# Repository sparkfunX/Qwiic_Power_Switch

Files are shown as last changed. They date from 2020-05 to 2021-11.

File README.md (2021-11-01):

# Qwiic Power Switch

A power switch for your Qwiic system.

Qwiic Power Switch (SPX-16740) (https://www.sparkfun.com/products/16740)

[Qwiic Power Switch (SPX-16740)](https://www.sparkfun.com/products/16740)

The Qwiic Power Switch is a simple little board which can be used to switch the power to your Qwiic
system. Many Qwiic boards draw very little current when not being used, but there are some that draw
significantly more. The power switch allows you to switch the power to those boards, so you can minimize the
current draw and extend your battery life when you need to.

When the Qwiic Power Switch is turned off, the I2C wires are isolated too which prevents the pull-up
resistors from feeding parasitic power to your Qwiic boards. The power switch can also be used to
isolate a 400kHz bus from a 100kHz bus; the slower bus can be disconnected during fast-mode communication
without disabling the power.

The heart of the Qwiic Power Switch is the TI PCA9536 4-Bit I2C I/O Expander. We have broken out GPIO pins
1 and 2 so you can use them as general purpose inputs or outputs.

## Repository Contents

- **/Documents** - Datasheets etc.
- **/Hardware** - Eagle design files
- **LICENSE.md** contains the licence information

## Library

- **[Arduino Library](https://github.com/sparkfun/SparkFun_Qwiic_Power_Switch_Arduino_Library)** - Library for the power switch

## License Information

This product is _**open source**_!

Please review the LICENSE.md file for license information.

If you have any questions or concerns on licensing, please contact technical support on our [SparkFun forums](https://forum.sparkfun.com/viewforum.php?f=123).

Distributed as-is; no warranty is given.

- Your friends at SparkFun.

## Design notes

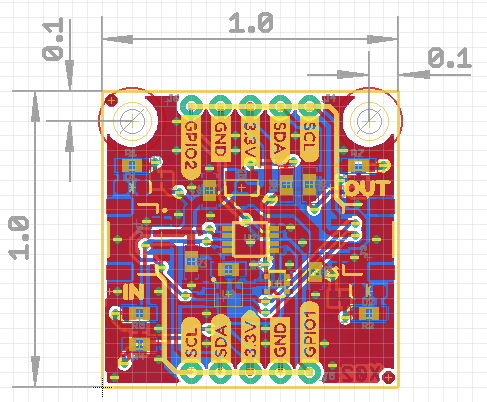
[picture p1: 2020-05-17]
img/Dimensions.PNG

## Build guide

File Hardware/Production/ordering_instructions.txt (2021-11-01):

panel size, 143x143mm
PCB thickness, 1.6mm
number of layers, 2
soldermask color, Black
silkscreen color, White
oz copper, 1oz
finish, HASL lead free
stencils, top
pcs per panel, 25
min trace width, 0.3048mm / 0.0120in
min drill size, 0.3048mm / 0.0120in

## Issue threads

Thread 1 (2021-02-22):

Investigate P-FET voltage drops

adamgarbo, 2021-02-22:
Hi @PaulZC,

A quick reminder, when time permits, to investigate the abnormally high voltage drops being experienced with the Qwiic Power Switch (QPS) when powering Qwiic devices that draw high amounts of current. Described in detail here: https://github.com/sparkfunX/Qwiic_Iridium_9603N/issues/1

Cheers,
Adam

Closed 2022-10-23.

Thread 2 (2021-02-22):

Investigate high quiescent draw

adamgarbo, 2021-02-22:
Hi @PaulZC,

Another quick note: I've been putting the Qwiic Power Switch (QPS) through its paces over the past few months and it's a very handy little board. If there are any future plans for it to "turn red", I believe it would also be worth investigating why the QPS draws upwards of ~100 uA when in its powered-down state. We've spoken about this in the past and I'd happy to try and help pin down the source of the draw.

Cheers,
Adam

Closed 2022-10-23.

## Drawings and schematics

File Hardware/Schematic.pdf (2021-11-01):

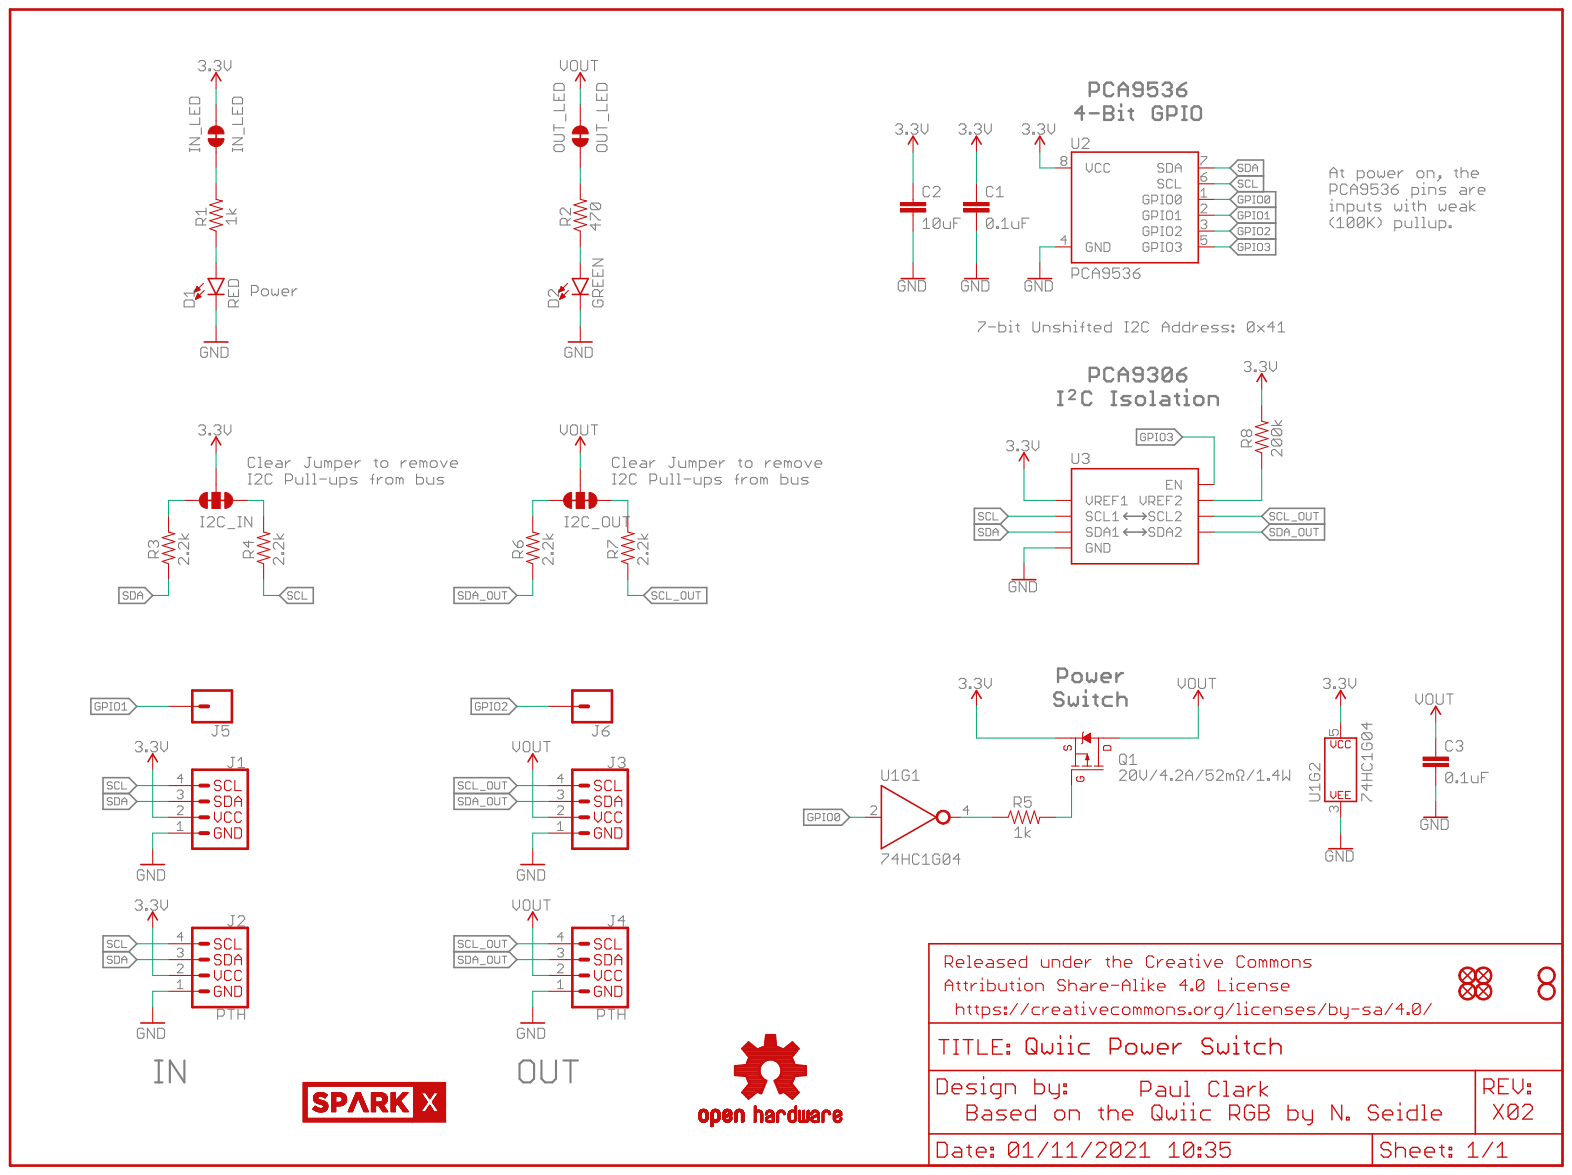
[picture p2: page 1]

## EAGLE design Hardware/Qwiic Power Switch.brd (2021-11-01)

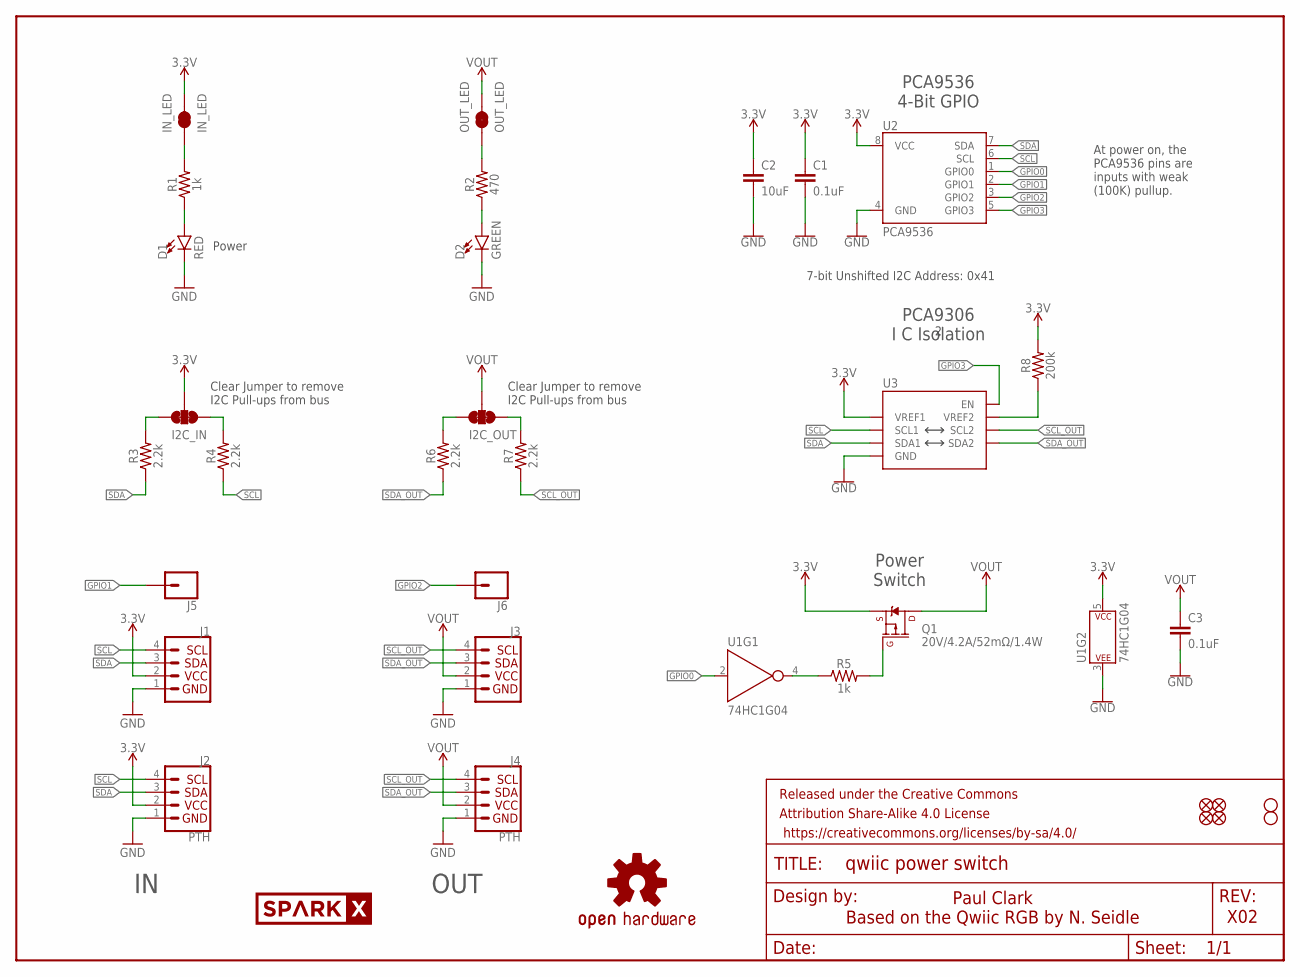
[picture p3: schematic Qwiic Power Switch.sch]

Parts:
C1, C3: 0.1uF; 0603
C2: 10uF; 0603
D1: RED; LED-0603
D2: GREEN; LED-0603
FRAME1: FRAME-LETTER; CREATIVE_COMMONS
I2C_IN, I2C_OUT: JUMPER-SMT_3_2-NC_TRACE_SILK; SMT-JUMPER_3_2-NC_TRACE_SILK
IN_LED: IN_LED; SMT-JUMPER_2_NC_TRACE_SILK
J1, J3: Qwiic Right Angle; JST04_1MM_RA
J2, J4: PTH; 1X04_NO_SILK
J5, J6: CONN_01PTH_NO_SILK_YES_STOP; 1X01_NO_SILK
JP1, JP2, JP5, JP6: FIDUCIAL1X2; FIDUCIAL-1X2
JP3, JP4: STAND-OFF
LOGO1: OSHW-LOGOMINI; OSHW-LOGO-MINI
OUT_LED: OUT_LED; SMT-JUMPER_2_NC_TRACE_SILK
Q1: 20V/4.2A/52mΩ/1.4W; SOT23-3
R1, R5: 1k; 0603
R2: 470; 0603
R3, R4, R6, R7: 2.2k; 0603
R8: 200k; 0603
U1: 74HC1G04; SOT353
U2: PCA9536; MSOP8
U3: PCA9306VSSOP_8PIN; VSSOP_8PIN
U$2: SPARKX-LOGO4; SPARKX-MEDIUM

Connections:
3.3V: C1.1, C2.1, I2C_IN.2, IN_LED.2, J1.2, J2.2, Q1.2 (S), R8.2, U1.5 (P$V+), U2.8 (VCC), U3.P2 (VREF1)
GND: C1.2, C2.2, C3.2, D1.C, D2.C, J1.1, J2.1, J3.1, J4.1, U1.3 (P$V-), U2.4 (GND), U3.P1 (GND)
GPIO0: U1.2 (A), U2.1 (GPIO0)
GPIO1: J5.1, U2.2 (GPIO1)
GPIO2: J6.1, U2.3 (GPIO2)
GPIO3: U2.5 (GPIO3), U3.P8 (EN)
unnamed: I2C_IN.1, R4.2
unnamed: I2C_IN.3, R3.2
unnamed: D1.A, R1.1
unnamed: IN_LED.1, R1.2
unnamed: R5.1, U1.4 (Y)
unnamed: Q1.1 (G), R5.2
unnamed: OUT_LED.1, R2.2
unnamed: I2C_OUT.1, R7.2
unnamed: D2.A, R2.1
unnamed: I2C_OUT.3, R6.2
unnamed: R8.1, U3.P7 (VREF2)
SCL: J1.4, J2.4, R4.1, U2.6 (SCL), U3.P3 (SCL1)
SCL_OUT: J3.4, J4.4, R7.1, U3.P6 (SCL2)
SDA: J1.3, J2.3, R3.1, U2.7 (SDA), U3.P4 (SDA1)
SDA_OUT: J3.3, J4.3, R6.1, U3.P5 (SDA2)
VOUT: C3.1, I2C_OUT.2, J3.2, J4.2, OUT_LED.2, Q1.3 (D)

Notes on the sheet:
Paul Clark Based on the Qwiic RGB by N. Seidle
X02
Clear Jumper to remove I2C Pull-ups from bus
Power
7-bit Unshifted I2C Address: 0x41
OUT
At power on, the PCA9536 pins are inputs with weak (100K) pullup.
PCA9536 4-Bit GPIO
PCA9306 I C Isolation
Power Switch

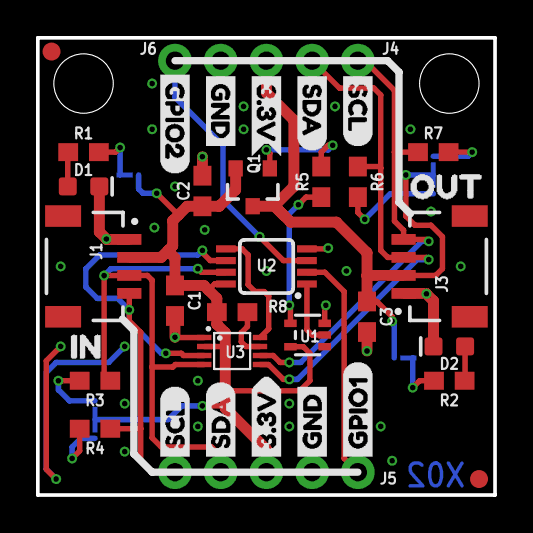
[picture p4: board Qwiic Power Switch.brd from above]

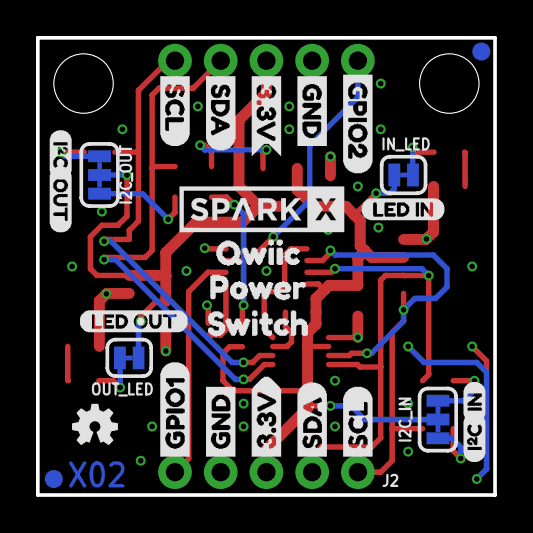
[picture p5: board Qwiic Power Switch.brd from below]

Board: 2 copper layers, 25.4 x 25.4 mm, 67 parts (28 on the bottom side), 22 nets.

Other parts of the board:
U$1, U$28: IN0
U$3, U$8, U$13, U$22: GND1
U$4, U$7, U$12, U$23: 3#3V0
U$5, U$11, U$15, U$27: SDA8
U$6, U$9, U$17, U$26: SCL9
U$10, U$18: I_SUPER2_C-()-03
U$14, U$31: OUT0
U$16, U$24: GPIO10
U$19: QWIIC0
U$20, U$25: GPIO20
U$29: LED_IN0
U$30: LED_OUT0
U$32: POWER0
U$34: SWITCH0

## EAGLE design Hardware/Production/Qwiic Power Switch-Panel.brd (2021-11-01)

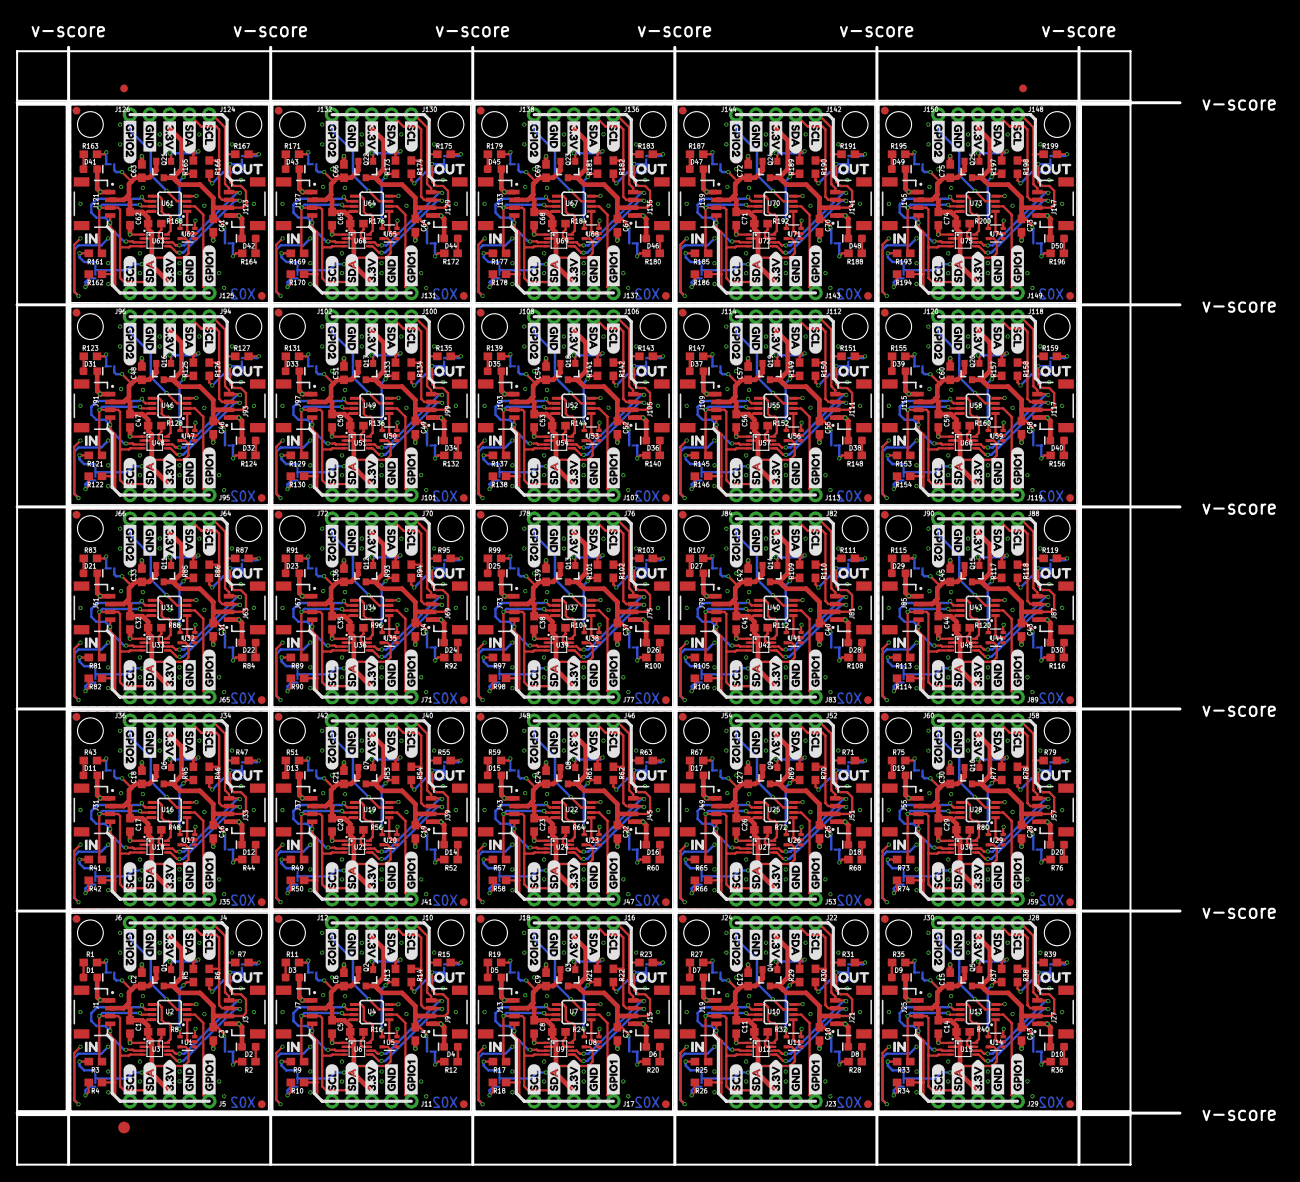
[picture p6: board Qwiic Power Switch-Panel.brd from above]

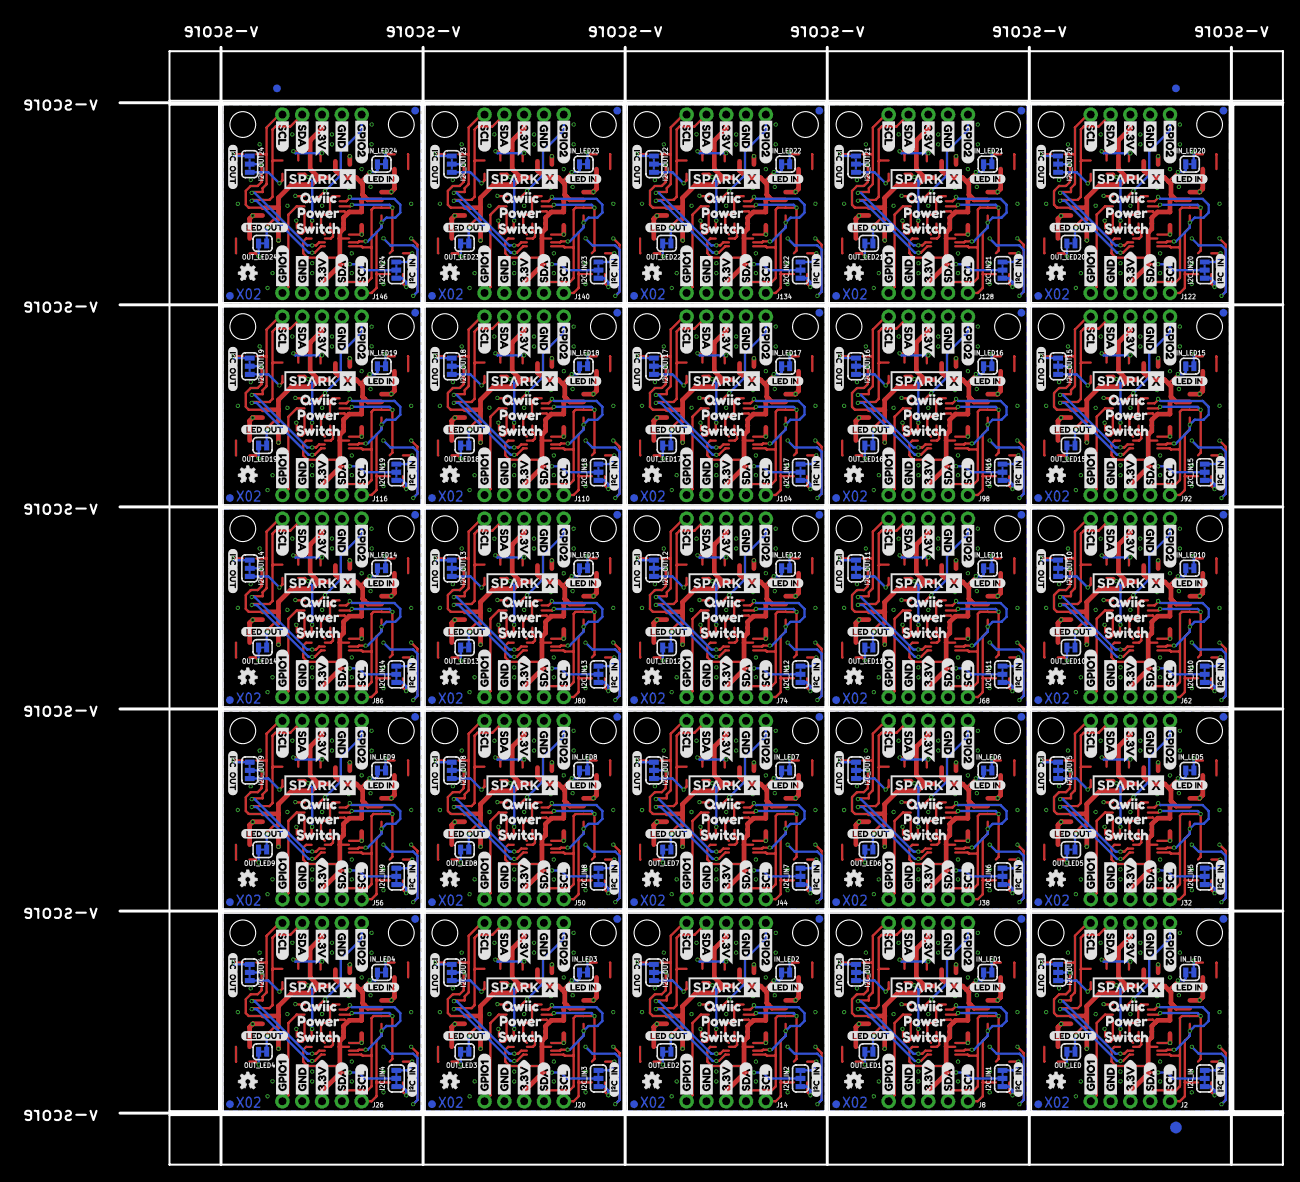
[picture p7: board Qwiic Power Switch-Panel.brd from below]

Board: 2 copper layers, 149.1 x 143.3 mm, 1656 parts (703 on the bottom side), 550 nets.

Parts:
C1, C3, C4, C5, C7, C8, C10, C11, C13, C14, C16, C17, C19, C20, C22, C23, C25, C26, C28, C29, C31, C32, C34, C35, C37, C38, C40, C41, C43, C44, C46, C47, C49, C50, C52, C53, C55, C56, C58, C59, C61, C62, C64, C65, C67, C68, C70, C71, C73, C74: 0.1uF; 0603
C2, C6, C9, C12, C15, C18, C21, C24, C27, C30, C33, C36, C39, C42, C45, C48, C51, C54, C57, C60, C63, C66, C69, C72, C75: 10uF; 0603
D1, D3, D5, D7, D9, D11, D13, D15, D17, D19, D21, D23, D25, D27, D29, D31, D33, D35, D37, D39, D41, D43, D45, D47, D49: RED; LED-0603
D2, D4, D6, D8, D10, D12, D14, D16, D18, D20, D22, D24, D26, D28, D30, D32, D34, D36, D38, D40, D42, D44, D46, D48, D50: GREEN; LED-0603
E$1, E$2, E$3, E$4: FIDUCIAL-1X2
E$5, E$6: FIDUCIAL-1.5X3
I2C_IN, I2C_IN1, I2C_IN2, I2C_IN3, I2C_IN4, I2C_IN5, I2C_IN6, I2C_IN7, I2C_IN8, I2C_IN9, I2C_IN10, I2C_IN11, I2C_IN12, I2C_IN13, I2C_IN14, I2C_IN15, I2C_IN16, I2C_IN17, I2C_IN18, I2C_IN19, I2C_IN20, I2C_IN21, I2C_IN22, I2C_IN23, I2C_IN24, I2C_OUT, I2C_OUT1, I2C_OUT2, I2C_OUT3, I2C_OUT4, I2C_OUT5, I2C_OUT6, I2C_OUT7, I2C_OUT8, I2C_OUT9, I2C_OUT10, I2C_OUT11, I2C_OUT12, I2C_OUT13, I2C_OUT14, I2C_OUT15, I2C_OUT16, I2C_OUT17, I2C_OUT18, I2C_OUT19, I2C_OUT20, I2C_OUT21, I2C_OUT22, I2C_OUT23, I2C_OUT24: JUMPER-SMT_3_2-NC_TRACE_SILK; SMT-JUMPER_3_2-NC_TRACE_SILK
IN_LED, IN_LED1, IN_LED2, IN_LED3, IN_LED4, IN_LED5, IN_LED6, IN_LED7, IN_LED8, IN_LED9, IN_LED10, IN_LED11, IN_LED12, IN_LED13, IN_LED14, IN_LED15, IN_LED16, IN_LED17, IN_LED18, IN_LED19, IN_LED20, IN_LED21, IN_LED22, IN_LED23, IN_LED24: IN_LED; SMT-JUMPER_2_NC_TRACE_SILK
J1, J3, J7, J9, J13, J15, J19, J21, J25, J27, J31, J33, J37, J39, J43, J45, J49, J51, J55, J57, J61, J63, J67, J69, J73, J75, J79, J81, J85, J87, J91, J93, J97, J99, J103, J105, J109, J111, J115, J117, J121, J123, J127, J129, J133, J135, J139, J141, J145, J147: Qwiic Right Angle; JST04_1MM_RA
J2, J4, J8, J10, J14, J16, J20, J22, J26, J28, J32, J34, J38, J40, J44, J46, J50, J52, J56, J58, J62, J64, J68, J70, J74, J76, J80, J82, J86, J88, J92, J94, J98, J100, J104, J106, J110, J112, J116, J118, J122, J124, J128, J130, J134, J136, J140, J142, J146, J148: PTH; 1X04_NO_SILK
J5, J6, J11, J12, J17, J18, J23, J24, J29, J30, J35, J36, J41, J42, J47, J48, J53, J54, J59, J60, J65, J66, J71, J72, J77, J78, J83, J84, J89, J90, J95, J96, J101, J102, J107, J108, J113, J114, J119, J120, J125, J126, J131, J132, J137, J138, J143, J144, J149, J150: 1X01_NO_SILK
JP1, JP2, JP5, JP6, JP9, JP10, JP11, JP12, JP15, JP16, JP17, JP18, JP21, JP22, JP23, JP24, JP27, JP28, JP29, JP30, JP33, JP34, JP35, JP36, JP39, JP40, JP41, JP42, JP45, JP46, JP47, JP48, JP51, JP52, JP53, JP54, JP57, JP58, JP59, JP60, JP63, JP64, JP65, JP66, JP69, JP70, JP71, JP72, JP75, JP76, JP77, JP78, JP81, JP82, JP83, JP84, JP87, JP88, JP89, JP90, JP93, JP94, JP95, JP96, JP99, JP100, JP101, JP102, JP105, JP106, JP107, JP108, JP111, JP112, JP113, JP114, JP117, JP118, JP119, JP120, JP123, JP124, JP125, JP126, JP129, JP130, JP131, JP132, JP135, JP136, JP137, JP138, JP141, JP142, JP143, JP144, JP147, JP148, JP149, JP150: FIDUCIAL1X2; FIDUCIAL-1X2
JP3, JP4, JP7, JP8, JP13, JP14, JP19, JP20, JP25, JP26, JP31, JP32, JP37, JP38, JP43, JP44, JP49, JP50, JP55, JP56, JP61, JP62, JP67, JP68, JP73, JP74, JP79, JP80, JP85, JP86, JP91, JP92, JP97, JP98, JP103, JP104, JP109, JP110, JP115, JP116, JP121, JP122, JP127, JP128, JP133, JP134, JP139, JP140, JP145, JP146: STAND-OFF
LOGO1, LOGO2, LOGO3, LOGO4, LOGO5, LOGO6, LOGO7, LOGO8, LOGO9, LOGO10, LOGO11, LOGO12, LOGO13, LOGO14, LOGO15, LOGO16, LOGO17, LOGO18, LOGO19, LOGO20, LOGO21, LOGO22, LOGO23, LOGO24, LOGO25: OSHW-LOGOMINI; OSHW-LOGO-MINI
OUT_LED, OUT_LED1, OUT_LED2, OUT_LED3, OUT_LED4, OUT_LED5, OUT_LED6, OUT_LED7, OUT_LED8, OUT_LED9, OUT_LED10, OUT_LED11, OUT_LED12, OUT_LED13, OUT_LED14, OUT_LED15, OUT_LED16, OUT_LED17, OUT_LED18, OUT_LED19, OUT_LED20, OUT_LED21, OUT_LED22, OUT_LED23, OUT_LED24: OUT_LED; SMT-JUMPER_2_NC_TRACE_SILK
Q1, Q2, Q3, Q4, Q5, Q6, Q7, Q8, Q9, Q10, Q11, Q12, Q13, Q14, Q15, Q16, Q17, Q18, Q19, Q20, Q21, Q22, Q23, Q24, Q25: 20V/4.2A/52mΩ/1.4W; SOT23-3
R1, R5, R11, R13, R19, R21, R27, R29, R35, R37, R43, R45, R51, R53, R59, R61, R67, R69, R75, R77, R83, R85, R91, R93, R99, R101, R107, R109, R115, R117, R123, R125, R131, R133, R139, R141, R147, R149, R155, R157, R163, R165, R171, R173, R179, R181, R187, R189, R195, R197: 1k; 0603
R2, R12, R20, R28, R36, R44, R52, R60, R68, R76, R84, R92, R100, R108, R116, R124, R132, R140, R148, R156, R164, R172, R180, R188, R196: 470; 0603
R3, R4, R6, R7, R9, R10, R14, R15, R17, R18, R22, R23, R25, R26, R30, R31, R33, R34, R38, R39, R41, R42, R46, R47, R49, R50, R54, R55, R57, R58, R62, R63, R65, R66, R70, R71, R73, R74, R78, R79, R81, R82, R86, R87, R89, R90, R94, R95, R97, R98, R102, R103, R105, R106, R110, R111, R113, R114, R118, R119, R121, R122, R126, R127, R129, R130, R134, R135, R137, R138, R142, R143, R145, R146, R150, R151, R153, R154, R158, R159, R161, R162, R166, R167, R169, R170, R174, R175, R177, R178, R182, R183, R185, R186, R190, R191, R193, R194, R198, R199: 2.2k; 0603
R8, R16, R24, R32, R40, R48, R56, R64, R72, R80, R88, R96, R104, R112, R120, R128, R136, R144, R152, R160, R168, R176, R184, R192, R200: 200k; 0603
U1, U5, U8, U11, U14, U17, U20, U23, U26, U29, U32, U35, U38, U41, U44, U47, U50, U53, U56, U59, U62, U65, U68, U71, U74: 74HC1G04; SOT353
U2, U4, U7, U10, U13, U16, U19, U22, U25, U28, U31, U34, U37, U40, U43, U46, U49, U52, U55, U58, U61, U64, U67, U70, U73: PCA9536; MSOP8
U3, U6, U9, U12, U15, U18, U21, U24, U27, U30, U33, U36, U39, U42, U45, U48, U51, U54, U57, U60, U63, U66, U69, U72, U75: VSSOP_8PIN
U$1, U$28, U$52, U$62, U$84, U$94, U$116, U$126, U$148, U$158, U$180, U$190, U$212, U$222, U$244, U$254, U$276, U$286, U$308, U$318, U$340, U$350, U$372, U$382, U$404, U$414, U$436, U$446, U$468, U$478, U$500, U$510, U$532, U$542, U$564, U$574, U$596, U$606, U$628, U$638, U$660, U$670, U$692, U$702, U$724, U$734, U$756, U$766, U$788, U$798: IN0
U$2, U$21, U$65, U$97, U$129, U$161, U$193, U$225, U$257, U$289, U$321, U$353, U$385, U$417, U$449, U$481, U$513, U$545, U$577, U$609, U$641, U$673, U$705, U$737, U$769: SPARKX-LOGO4; SPARKX-MEDIUM
U$3, U$8, U$13, U$22, U$33, U$37, U$41, U$44, U$66, U$69, U$73, U$76, U$98, U$101, U$105, U$108, U$130, U$133, U$137, U$140, U$162, U$165, U$169, U$172, U$194, U$197, U$201, U$204, U$226, U$229, U$233, U$236, U$258, U$261, U$265, U$268, U$290, U$293, U$297, U$300, U$322, U$325, U$329, U$332, U$354, U$357, U$361, U$364, U$386, U$389, U$393, U$396, U$418, U$421, U$425, U$428, U$450, U$453, U$457, U$460, U$482, U$485, U$489, U$492, U$514, U$517, U$521, U$524, U$546, U$549, U$553, U$556, U$578, U$581, U$585, U$588, U$610, U$613, U$617, U$620, U$642, U$645, U$649, U$652, U$674, U$677, U$681, U$684, U$706, U$709, U$713, U$716, U$738, U$741, U$745, U$748, U$770, U$773, U$777, U$780: GND1
U$4, U$7, U$12, U$23, U$48, U$49, U$60, U$61, U$80, U$81, U$92, U$93, U$112, U$113, U$124, U$125, U$144, U$145, U$156, U$157, U$176, U$177, U$188, U$189, U$208, U$209, U$220, U$221, U$240, U$241, U$252, U$253, U$272, U$273, U$284, U$285, U$304, U$305, U$316, U$317, U$336, U$337, U$348, U$349, U$368, U$369, U$380, U$381, U$400, U$401, U$412, U$413, U$432, U$433, U$444, U$445, U$464, U$465, U$476, U$477, U$496, U$497, U$508, U$509, U$528, U$529, U$540, U$541, U$560, U$561, U$572, U$573, U$592, U$593, U$604, U$605, U$624, U$625, U$636, U$637, U$656, U$657, U$668, U$669, U$688, U$689, U$700, U$701, U$720, U$721, U$732, U$733, U$752, U$753, U$764, U$765, U$784, U$785, U$796, U$797: 3#3V0
U$5, U$11, U$15, U$27, U$36, U$38, U$43, U$45, U$68, U$70, U$75, U$77, U$100, U$102, U$107, U$109, U$132, U$134, U$139, U$141, U$164, U$166, U$171, U$173, U$196, U$198, U$203, U$205, U$228, U$230, U$235, U$237, U$260, U$262, U$267, U$269, U$292, U$294, U$299, U$301, U$324, U$326, U$331, U$333, U$356, U$358, U$363, U$365, U$388, U$390, U$395, U$397, U$420, U$422, U$427, U$429, U$452, U$454, U$459, U$461, U$484, U$486, U$491, U$493, U$516, U$518, U$523, U$525, U$548, U$550, U$555, U$557, U$580, U$582, U$587, U$589, U$612, U$614, U$619, U$621, U$644, U$646, U$651, U$653, U$676, U$678, U$683, U$685, U$708, U$710, U$715, U$717, U$740, U$742, U$747, U$749, U$772, U$774, U$779, U$781: SDA8
U$6, U$9, U$17, U$26, U$35, U$39, U$42, U$46, U$67, U$71, U$74, U$78, U$99, U$103, U$106, U$110, U$131, U$135, U$138, U$142, U$163, U$167, U$170, U$174, U$195, U$199, U$202, U$206, U$227, U$231, U$234, U$238, U$259, U$263, U$266, U$270, U$291, U$295, U$298, U$302, U$323, U$327, U$330, U$334, U$355, U$359, U$362, U$366, U$387, U$391, U$394, U$398, U$419, U$423, U$426, U$430, U$451, U$455, U$458, U$462, U$483, U$487, U$490, U$494, U$515, U$519, U$522, U$526, U$547, U$551, U$554, U$558, U$579, U$583, U$586, U$590, U$611, U$615, U$618, U$622, U$643, U$647, U$650, U$654, U$675, U$679, U$682, U$686, U$707, U$711, U$714, U$718, U$739, U$743, U$746, U$750, U$771, U$775, U$778, U$782: SCL9
U$10, U$18, U$40, U$64, U$72, U$96, U$104, U$128, U$136, U$160, U$168, U$192, U$200, U$224, U$232, U$256, U$264, U$288, U$296, U$320, U$328, U$352, U$360, U$384, U$392, U$416, U$424, U$448, U$456, U$480, U$488, U$512, U$520, U$544, U$552, U$576, U$584, U$608, U$616, U$640, U$648, U$672, U$680, U$704, U$712, U$736, U$744, U$768, U$776, U$800: I_SUPER2_C-()-03
U$14, U$31, U$55, U$63, U$87, U$95, U$119, U$127, U$151, U$159, U$183, U$191, U$215, U$223, U$247, U$255, U$279, U$287, U$311, U$319, U$343, U$351, U$375, U$383, U$407, U$415, U$439, U$447, U$471, U$479, U$503, U$511, U$535, U$543, U$567, U$575, U$599, U$607, U$631, U$639, U$663, U$671, U$695, U$703, U$727, U$735, U$759, U$767, U$791, U$799: OUT0
U$16, U$24, U$50, U$58, U$82, U$90, U$114, U$122, U$146, U$154, U$178, U$186, U$210, U$218, U$242, U$250, U$274, U$282, U$306, U$314, U$338, U$346, U$370, U$378, U$402, U$410, U$434, U$442, U$466, U$474, U$498, U$506, U$530, U$538, U$562, U$570, U$594, U$602, U$626, U$634, U$658, U$666, U$690, U$698, U$722, U$730, U$754, U$762, U$786, U$794: GPIO10
U$19, U$47, U$79, U$111, U$143, U$175, U$207, U$239, U$271, U$303, U$335, U$367, U$399, U$431, U$463, U$495, U$527, U$559, U$591, U$623, U$655, U$687, U$719, U$751, U$783: QWIIC0
U$20, U$25, U$51, U$59, U$83, U$91, U$115, U$123, U$147, U$155, U$179, U$187, U$211, U$219, U$243, U$251, U$275, U$283, U$307, U$315, U$339, U$347, U$371, U$379, U$403, U$411, U$435, U$443, U$467, U$475, U$499, U$507, U$531, U$539, U$563, U$571, U$595, U$603, U$627, U$635, U$659, U$667, U$691, U$699, U$723, U$731, U$755, U$763, U$787, U$795: GPIO20
U$29, U$53, U$85, U$117, U$149, U$181, U$213, U$245, U$277, U$309, U$341, U$373, U$405, U$437, U$469, U$501, U$533, U$565, U$597, U$629, U$661, U$693, U$725, U$757, U$789: LED_IN0
U$30, U$54, U$86, U$118, U$150, U$182, U$214, U$246, U$278, U$310, U$342, U$374, U$406, U$438, U$470, U$502, U$534, U$566, U$598, U$630, U$662, U$694, U$726, U$758, U$790: LED_OUT0
U$32, U$56, U$88, U$120, U$152, U$184, U$216, U$248, U$280, U$312, U$344, U$376, U$408, U$440, U$472, U$504, U$536, U$568, U$600, U$632, U$664, U$696, U$728, U$760, U$792: POWER0
U$34, U$57, U$89, U$121, U$153, U$185, U$217, U$249, U$281, U$313, U$345, U$377, U$409, U$441, U$473, U$505, U$537, U$569, U$601, U$633, U$665, U$697, U$729, U$761, U$793: SWITCH0

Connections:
3.3V: C1.1, C2.1, I2C_IN.2, IN_LED.2, J1.2, J2.2, Q1.2, R8.2, U1.5, U2.8, U3.P2
3.3V1: C5.1, C6.1, I2C_IN1.2, IN_LED1.2, J7.2, J8.2, Q2.2, R16.2, U4.8, U5.5, U6.P2
3.3V2: C8.1, C9.1, I2C_IN2.2, IN_LED2.2, J13.2, J14.2, Q3.2, R24.2, U7.8, U8.5, U9.P2
3.3V3: C11.1, C12.1, I2C_IN3.2, IN_LED3.2, J19.2, J20.2, Q4.2, R32.2, U10.8, U11.5, U12.P2
3.3V4: C14.1, C15.1, I2C_IN4.2, IN_LED4.2, J25.2, J26.2, Q5.2, R40.2, U13.8, U14.5, U15.P2
3.3V5: C17.1, C18.1, I2C_IN5.2, IN_LED5.2, J31.2, J32.2, Q6.2, R48.2, U16.8, U17.5, U18.P2
3.3V6: C20.1, C21.1, I2C_IN6.2, IN_LED6.2, J37.2, J38.2, Q7.2, R56.2, U19.8, U20.5, U21.P2
3.3V7: C23.1, C24.1, I2C_IN7.2, IN_LED7.2, J43.2, J44.2, Q8.2, R64.2, U22.8, U23.5, U24.P2
3.3V8: C26.1, C27.1, I2C_IN8.2, IN_LED8.2, J49.2, J50.2, Q9.2, R72.2, U25.8, U26.5, U27.P2
3.3V9: C29.1, C30.1, I2C_IN9.2, IN_LED9.2, J55.2, J56.2, Q10.2, R80.2, U28.8, U29.5, U30.P2
3.3V10: C32.1, C33.1, I2C_IN10.2, IN_LED10.2, J61.2, J62.2, Q11.2, R88.2, U31.8, U32.5, U33.P2
3.3V11: C35.1, C36.1, I2C_IN11.2, IN_LED11.2, J67.2, J68.2, Q12.2, R96.2, U34.8, U35.5, U36.P2
3.3V12: C38.1, C39.1, I2C_IN12.2, IN_LED12.2, J73.2, J74.2, Q13.2, R104.2, U37.8, U38.5, U39.P2
3.3V13: C41.1, C42.1, I2C_IN13.2, IN_LED13.2, J79.2, J80.2, Q14.2, R112.2, U40.8, U41.5, U42.P2
3.3V14: C44.1, C45.1, I2C_IN14.2, IN_LED14.2, J85.2, J86.2, Q15.2, R120.2, U43.8, U44.5, U45.P2
3.3V15: C47.1, C48.1, I2C_IN15.2, IN_LED15.2, J91.2, J92.2, Q16.2, R128.2, U46.8, U47.5, U48.P2
3.3V16: C50.1, C51.1, I2C_IN16.2, IN_LED16.2, J97.2, J98.2, Q17.2, R136.2, U49.8, U50.5, U51.P2
3.3V17: C53.1, C54.1, I2C_IN17.2, IN_LED17.2, J103.2, J104.2, Q18.2, R144.2, U52.8, U53.5, U54.P2
3.3V18: C56.1, C57.1, I2C_IN18.2, IN_LED18.2, J109.2, J110.2, Q19.2, R152.2, U55.8, U56.5, U57.P2
3.3V19: C59.1, C60.1, I2C_IN19.2, IN_LED19.2, J115.2, J116.2, Q20.2, R160.2, U58.8, U59.5, U60.P2
3.3V20: C62.1, C63.1, I2C_IN20.2, IN_LED20.2, J121.2, J122.2, Q21.2, R168.2, U61.8, U62.5, U63.P2
3.3V21: C65.1, C66.1, I2C_IN21.2, IN_LED21.2, J127.2, J128.2, Q22.2, R176.2, U64.8, U65.5, U66.P2
3.3V22: C68.1, C69.1, I2C_IN22.2, IN_LED22.2, J133.2, J134.2, Q23.2, R184.2, U67.8, U68.5, U69.P2
3.3V23: C71.1, C72.1, I2C_IN23.2, IN_LED23.2, J139.2, J140.2, Q24.2, R192.2, U70.8, U71.5, U72.P2
3.3V24: C74.1, C75.1, I2C_IN24.2, IN_LED24.2, J145.2, J146.2, Q25.2, R200.2, U73.8, U74.5, U75.P2
GND: C1.2, C2.2, C3.2, D1.C, D2.C, J1.1, J2.1, J3.1, J4.1, U1.3, U2.4, U3.P1
GND1: C4.2, C5.2, C6.2, D3.C, D4.C, J7.1, J8.1, J9.1, J10.1, U4.4, U5.3, U6.P1
GND2: C7.2, C8.2, C9.2, D5.C, D6.C, J13.1, J14.1, J15.1, J16.1, U7.4, U8.3, U9.P1
GND3: C10.2, C11.2, C12.2, D7.C, D8.C, J19.1, J20.1, J21.1, J22.1, U10.4, U11.3, U12.P1
GND4: C13.2, C14.2, C15.2, D9.C, D10.C, J25.1, J26.1, J27.1, J28.1, U13.4, U14.3, U15.P1
GND5: C16.2, C17.2, C18.2, D11.C, D12.C, J31.1, J32.1, J33.1, J34.1, U16.4, U17.3, U18.P1
GND6: C19.2, C20.2, C21.2, D13.C, D14.C, J37.1, J38.1, J39.1, J40.1, U19.4, U20.3, U21.P1
GND7: C22.2, C23.2, C24.2, D15.C, D16.C, J43.1, J44.1, J45.1, J46.1, U22.4, U23.3, U24.P1
GND8: C25.2, C26.2, C27.2, D17.C, D18.C, J49.1, J50.1, J51.1, J52.1, U25.4, U26.3, U27.P1
GND9: C28.2, C29.2, C30.2, D19.C, D20.C, J55.1, J56.1, J57.1, J58.1, U28.4, U29.3, U30.P1
GND10: C31.2, C32.2, C33.2, D21.C, D22.C, J61.1, J62.1, J63.1, J64.1, U31.4, U32.3, U33.P1
GND11: C34.2, C35.2, C36.2, D23.C, D24.C, J67.1, J68.1, J69.1, J70.1, U34.4, U35.3, U36.P1
GND12: C37.2, C38.2, C39.2, D25.C, D26.C, J73.1, J74.1, J75.1, J76.1, U37.4, U38.3, U39.P1
GND13: C40.2, C41.2, C42.2, D27.C, D28.C, J79.1, J80.1, J81.1, J82.1, U40.4, U41.3, U42.P1
GND14: C43.2, C44.2, C45.2, D29.C, D30.C, J85.1, J86.1, J87.1, J88.1, U43.4, U44.3, U45.P1
GND15: C46.2, C47.2, C48.2, D31.C, D32.C, J91.1, J92.1, J93.1, J94.1, U46.4, U47.3, U48.P1
GND16: C49.2, C50.2, C51.2, D33.C, D34.C, J97.1, J98.1, J99.1, J100.1, U49.4, U50.3, U51.P1
GND17: C52.2, C53.2, C54.2, D35.C, D36.C, J103.1, J104.1, J105.1, J106.1, U52.4, U53.3, U54.P1
GND18: C55.2, C56.2, C57.2, D37.C, D38.C, J109.1, J110.1, J111.1, J112.1, U55.4, U56.3, U57.P1
GND19: C58.2, C59.2, C60.2, D39.C, D40.C, J115.1, J116.1, J117.1, J118.1, U58.4, U59.3, U60.P1
GND20: C61.2, C62.2, C63.2, D41.C, D42.C, J121.1, J122.1, J123.1, J124.1, U61.4, U62.3, U63.P1
GND21: C64.2, C65.2, C66.2, D43.C, D44.C, J127.1, J128.1, J129.1, J130.1, U64.4, U65.3, U66.P1
GND22: C67.2, C68.2, C69.2, D45.C, D46.C, J133.1, J134.1, J135.1, J136.1, U67.4, U68.3, U69.P1
GND23: C70.2, C71.2, C72.2, D47.C, D48.C, J139.1, J140.1, J141.1, J142.1, U70.4, U71.3, U72.P1
GND24: C73.2, C74.2, C75.2, D49.C, D50.C, J145.1, J146.1, J147.1, J148.1, U73.4, U74.3, U75.P1
GPIO0: U1.2, U2.1
GPIO1: J5.1, U2.2
GPIO2: J6.1, U2.3
GPIO3: U2.5, U3.P8
GPIO4: U4.1, U5.2
GPIO5: J11.1, U4.2
GPIO6: J12.1, U4.3
GPIO7: U4.5, U6.P8
GPIO8: U7.1, U8.2
GPIO9: J17.1, U7.2
GPIO10: J18.1, U7.3
GPIO11: U7.5, U9.P8
GPIO12: U10.1, U11.2
GPIO13: J23.1, U10.2
GPIO14: J24.1, U10.3
GPIO15: U10.5, U12.P8
GPIO16: U13.1, U14.2
GPIO17: J29.1, U13.2
GPIO18: J30.1, U13.3
GPIO19: U13.5, U15.P8
GPIO20: U16.1, U17.2
GPIO21: J35.1, U16.2
GPIO22: J36.1, U16.3
GPIO23: U16.5, U18.P8
GPIO24: U19.1, U20.2
GPIO25: J41.1, U19.2
GPIO26: J42.1, U19.3
GPIO27: U19.5, U21.P8
GPIO28: U22.1, U23.2
GPIO29: J47.1, U22.2
GPIO30: J48.1, U22.3
GPIO31: U22.5, U24.P8
GPIO32: U25.1, U26.2
GPIO33: J53.1, U25.2
GPIO34: J54.1, U25.3
GPIO35: U25.5, U27.P8
GPIO36: U28.1, U29.2
GPIO37: J59.1, U28.2
GPIO38: J60.1, U28.3
GPIO39: U28.5, U30.P8
GPIO40: U31.1, U32.2
GPIO41: J65.1, U31.2
GPIO42: J66.1, U31.3
GPIO43: U31.5, U33.P8
GPIO44: U34.1, U35.2
GPIO45: J71.1, U34.2
GPIO46: J72.1, U34.3
GPIO47: U34.5, U36.P8
GPIO48: U37.1, U38.2
GPIO49: J77.1, U37.2
GPIO50: J78.1, U37.3
GPIO51: U37.5, U39.P8
GPIO52: U40.1, U41.2
GPIO53: J83.1, U40.2
GPIO54: J84.1, U40.3
GPIO55: U40.5, U42.P8
GPIO56: U43.1, U44.2
GPIO57: J89.1, U43.2
GPIO58: J90.1, U43.3
GPIO59: U43.5, U45.P8
GPIO60: U46.1, U47.2
GPIO61: J95.1, U46.2
GPIO62: J96.1, U46.3
GPIO63: U46.5, U48.P8
GPIO64: U49.1, U50.2
GPIO65: J101.1, U49.2
GPIO66: J102.1, U49.3
GPIO67: U49.5, U51.P8
GPIO68: U52.1, U53.2
GPIO69: J107.1, U52.2
GPIO70: J108.1, U52.3
GPIO71: U52.5, U54.P8
GPIO72: U55.1, U56.2
GPIO73: J113.1, U55.2
GPIO74: J114.1, U55.3
GPIO75: U55.5, U57.P8
GPIO76: U58.1, U59.2
GPIO77: J119.1, U58.2
GPIO78: J120.1, U58.3
GPIO79: U58.5, U60.P8
GPIO80: U61.1, U62.2
GPIO81: J125.1, U61.2
GPIO82: J126.1, U61.3
GPIO83: U61.5, U63.P8
GPIO84: U64.1, U65.2
GPIO85: J131.1, U64.2
GPIO86: J132.1, U64.3
GPIO87: U64.5, U66.P8
GPIO88: U67.1, U68.2
GPIO89: J137.1, U67.2
GPIO90: J138.1, U67.3
GPIO91: U67.5, U69.P8
GPIO92: U70.1, U71.2
GPIO93: J143.1, U70.2
GPIO94: J144.1, U70.3
GPIO95: U70.5, U72.P8
GPIO96: U73.1, U74.2
GPIO97: J149.1, U73.2
GPIO98: J150.1, U73.3
GPIO99: U73.5, U75.P8
unnamed: I2C_IN.1, R4.2
unnamed: I2C_IN.3, R3.2
unnamed: D1.A, R1.1
unnamed: IN_LED.1, R1.2
unnamed: R5.1, U1.4
unnamed: Q1.1, R5.2
unnamed: OUT_LED.1, R2.2
unnamed: I2C_OUT.1, R7.2
unnamed: D2.A, R2.1
unnamed: I2C_OUT.3, R6.2
unnamed: I2C_IN1.1, R10.2
unnamed: R8.1, U3.P7
unnamed: I2C_IN1.3, R9.2
unnamed: D3.A, R11.1
unnamed: D4.A, R12.1
unnamed: IN_LED1.1, R11.2
unnamed: OUT_LED1.1, R12.2
unnamed: R13.1, U5.4
unnamed: Q2.1, R13.2
unnamed: I2C_OUT1.1, R15.2
unnamed: I2C_OUT1.3, R14.2
unnamed: R16.1, U6.P7
unnamed: I2C_IN2.1, R18.2
unnamed: I2C_IN2.3, R17.2
unnamed: D5.A, R19.1
unnamed: D6.A, R20.1
unnamed: IN_LED2.1, R19.2
unnamed: OUT_LED2.1, R20.2
unnamed: R21.1, U8.4
unnamed: Q3.1, R21.2
unnamed: I2C_OUT2.1, R23.2
unnamed: I2C_OUT2.3, R22.2
unnamed: R24.1, U9.P7
unnamed: I2C_IN3.1, R26.2
unnamed: I2C_IN3.3, R25.2
unnamed: D7.A, R27.1
unnamed: D8.A, R28.1
unnamed: IN_LED3.1, R27.2
unnamed: OUT_LED3.1, R28.2
unnamed: R29.1, U11.4
unnamed: Q4.1, R29.2
unnamed: I2C_OUT3.1, R31.2
unnamed: I2C_OUT3.3, R30.2
unnamed: R32.1, U12.P7
unnamed: I2C_IN4.1, R34.2
unnamed: I2C_IN4.3, R33.2
unnamed: D9.A, R35.1
unnamed: D10.A, R36.1
unnamed: IN_LED4.1, R35.2
unnamed: OUT_LED4.1, R36.2
unnamed: R37.1, U14.4
unnamed: Q5.1, R37.2
unnamed: I2C_OUT4.1, R39.2
unnamed: I2C_OUT4.3, R38.2
unnamed: R40.1, U15.P7
unnamed: I2C_IN5.1, R42.2
unnamed: I2C_IN5.3, R41.2
unnamed: D11.A, R43.1
unnamed: D12.A, R44.1
unnamed: IN_LED5.1, R43.2
unnamed: OUT_LED5.1, R44.2
unnamed: R45.1, U17.4
unnamed: Q6.1, R45.2
unnamed: I2C_OUT5.1, R47.2
unnamed: I2C_OUT5.3, R46.2
unnamed: R48.1, U18.P7
unnamed: I2C_IN6.1, R50.2
unnamed: I2C_IN6.3, R49.2
unnamed: D13.A, R51.1
unnamed: D14.A, R52.1
unnamed: IN_LED6.1, R51.2
unnamed: OUT_LED6.1, R52.2
unnamed: R53.1, U20.4
unnamed: Q7.1, R53.2
unnamed: I2C_OUT6.1, R55.2
unnamed: I2C_OUT6.3, R54.2
unnamed: R56.1, U21.P7
unnamed: I2C_IN7.1, R58.2
unnamed: I2C_IN7.3, R57.2
unnamed: D15.A, R59.1
unnamed: D16.A, R60.1
unnamed: IN_LED7.1, R59.2
unnamed: OUT_LED7.1, R60.2
unnamed: R61.1, U23.4
unnamed: Q8.1, R61.2
unnamed: I2C_OUT7.1, R63.2
unnamed: I2C_OUT7.3, R62.2
unnamed: R64.1, U24.P7
unnamed: I2C_IN8.1, R66.2
unnamed: I2C_IN8.3, R65.2
unnamed: D17.A, R67.1
unnamed: D18.A, R68.1
unnamed: IN_LED8.1, R67.2
unnamed: OUT_LED8.1, R68.2
unnamed: R69.1, U26.4
unnamed: Q9.1, R69.2
unnamed: I2C_OUT8.1, R71.2
unnamed: I2C_OUT8.3, R70.2
unnamed: R72.1, U27.P7
unnamed: I2C_IN9.1, R74.2
unnamed: I2C_IN9.3, R73.2
unnamed: D19.A, R75.1
unnamed: D20.A, R76.1
unnamed: IN_LED9.1, R75.2
unnamed: OUT_LED9.1, R76.2
unnamed: R77.1, U29.4
unnamed: Q10.1, R77.2
unnamed: I2C_OUT9.1, R79.2
unnamed: I2C_OUT9.3, R78.2
unnamed: R80.1, U30.P7
unnamed: I2C_IN10.1, R82.2
unnamed: I2C_IN10.3, R81.2
unnamed: D21.A, R83.1
unnamed: D22.A, R84.1
unnamed: IN_LED10.1, R83.2
unnamed: OUT_LED10.1, R84.2
unnamed: R85.1, U32.4
unnamed: Q11.1, R85.2
unnamed: I2C_OUT10.1, R87.2
unnamed: I2C_OUT10.3, R86.2
unnamed: R88.1, U33.P7
unnamed: I2C_IN11.1, R90.2
unnamed: I2C_IN11.3, R89.2
unnamed: D23.A, R91.1
unnamed: D24.A, R92.1
unnamed: IN_LED11.1, R91.2
unnamed: OUT_LED11.1, R92.2
unnamed: R93.1, U35.4
unnamed: Q12.1, R93.2
unnamed: I2C_OUT11.1, R95.2
unnamed: I2C_OUT11.3, R94.2
unnamed: R96.1, U36.P7
unnamed: I2C_IN12.1, R98.2
unnamed: I2C_IN12.3, R97.2
unnamed: D25.A, R99.1
unnamed: D26.A, R100.1
unnamed: IN_LED12.1, R99.2
unnamed: OUT_LED12.1, R100.2
unnamed: R101.1, U38.4
unnamed: Q13.1, R101.2
unnamed: I2C_OUT12.1, R103.2
unnamed: I2C_OUT12.3, R102.2
unnamed: R104.1, U39.P7
unnamed: I2C_IN13.1, R106.2
unnamed: I2C_IN13.3, R105.2
unnamed: D27.A, R107.1
unnamed: D28.A, R108.1
unnamed: IN_LED13.1, R107.2
unnamed: OUT_LED13.1, R108.2
unnamed: R109.1, U41.4
unnamed: Q14.1, R109.2
unnamed: I2C_OUT13.1, R111.2
unnamed: I2C_OUT13.3, R110.2
unnamed: R112.1, U42.P7
unnamed: I2C_IN14.1, R114.2
unnamed: I2C_IN14.3, R113.2
unnamed: D29.A, R115.1
unnamed: D30.A, R116.1
unnamed: IN_LED14.1, R115.2
unnamed: OUT_LED14.1, R116.2
unnamed: R117.1, U44.4
unnamed: Q15.1, R117.2
unnamed: I2C_OUT14.1, R119.2
unnamed: I2C_OUT14.3, R118.2
unnamed: R120.1, U45.P7
unnamed: I2C_IN15.1, R122.2
unnamed: I2C_IN15.3, R121.2
unnamed: D31.A, R123.1
unnamed: D32.A, R124.1
unnamed: IN_LED15.1, R123.2
unnamed: OUT_LED15.1, R124.2
unnamed: R125.1, U47.4
unnamed: Q16.1, R125.2
unnamed: I2C_OUT15.1, R127.2
unnamed: I2C_OUT15.3, R126.2
unnamed: R128.1, U48.P7
unnamed: I2C_IN16.1, R130.2
unnamed: I2C_IN16.3, R129.2
unnamed: D33.A, R131.1
unnamed: D34.A, R132.1
unnamed: IN_LED16.1, R131.2
unnamed: OUT_LED16.1, R132.2
unnamed: R133.1, U50.4
unnamed: Q17.1, R133.2
unnamed: I2C_OUT16.1, R135.2
unnamed: I2C_OUT16.3, R134.2
unnamed: R136.1, U51.P7
unnamed: I2C_IN17.1, R138.2
unnamed: I2C_IN17.3, R137.2
unnamed: D35.A, R139.1
unnamed: D36.A, R140.1
unnamed: IN_LED17.1, R139.2
unnamed: OUT_LED17.1, R140.2
unnamed: R141.1, U53.4
unnamed: Q18.1, R141.2
unnamed: I2C_OUT17.1, R143.2
unnamed: I2C_OUT17.3, R142.2
unnamed: R144.1, U54.P7
unnamed: I2C_IN18.1, R146.2
unnamed: I2C_IN18.3, R145.2
unnamed: D37.A, R147.1
unnamed: D38.A, R148.1
unnamed: IN_LED18.1, R147.2
unnamed: OUT_LED18.1, R148.2
unnamed: R149.1, U56.4
unnamed: Q19.1, R149.2
unnamed: I2C_OUT18.1, R151.2
unnamed: I2C_OUT18.3, R150.2
unnamed: R152.1, U57.P7
unnamed: I2C_IN19.1, R154.2
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

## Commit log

2020-04-24 Finishing touches...
    [Qwiic Power Switch.brd, Qwiic Power Switch.sch]
2020-05-17 Version X02
    [Qwiic Power Switch.brd, Qwiic Power Switch.sch]
2020-05-18 Add x01 panel files
    [Qwiic Power Switch-Panel.GBL, Qwiic Power Switch-Panel.GBO, Qwiic Power Switch-Panel.GBP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]
2020-05-18 Not quite finished - need to add the PCA9306 tPlace outline
    [Qwiic Power Switch.brd, Qwiic Power Switch.sch]
2020-05-19 X02 ready for manufacture
    [Qwiic Power Switch.brd, Qwiic Power Switch.sch]
2020-05-19 Add x02 production files
    [Qwiic Power Switch-Panel.brd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]
2020-06-18 Create Qwiic Power Switch.zip
2021-11-01 Remove New_Parts.lbr
    [Qwiic Power Switch-Panel.brd, Qwiic Power Switch.brd, Qwiic Power Switch.sch]

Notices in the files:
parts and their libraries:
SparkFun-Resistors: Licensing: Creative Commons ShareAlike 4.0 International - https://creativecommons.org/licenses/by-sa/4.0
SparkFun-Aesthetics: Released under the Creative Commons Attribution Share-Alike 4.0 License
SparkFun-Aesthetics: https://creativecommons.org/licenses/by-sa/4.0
